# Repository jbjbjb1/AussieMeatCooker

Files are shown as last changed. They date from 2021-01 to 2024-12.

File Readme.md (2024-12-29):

# Readme

The purpose of this project is to make a device to monitor bbq air and meat temperature to cook the perfect steak! The image below shows the current progress of the project - when a perfect steak is shown, this project is functional!

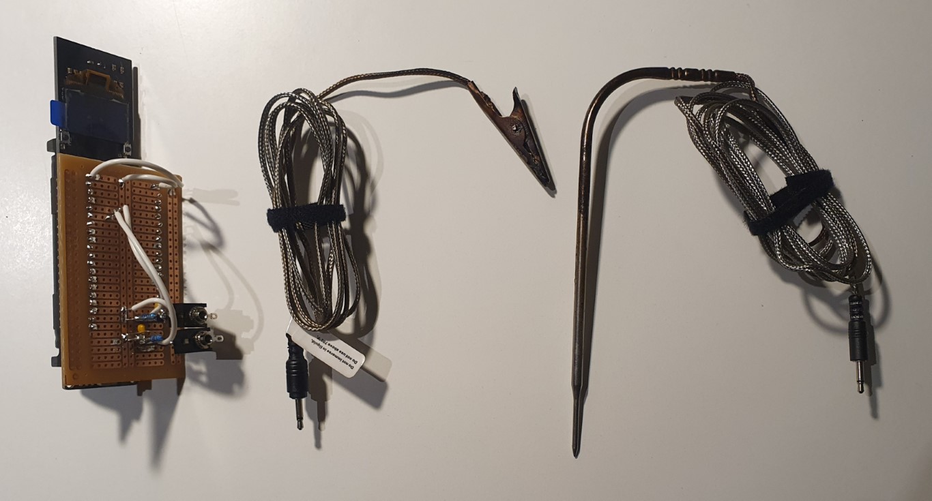
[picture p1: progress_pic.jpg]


This project is currently functional and the temperature reading has an accuracy of +/-1 deg C. It uses bluetooth to communicate via bluetooth serial (e.g. android app: https://play.google.com/store/apps/details?id=de.kai_morich.serial_bluetooth_terminal&hl=en_AU&gl=US). This project initially started as an arduino based device and spring boarded off some great work done here: https://forum.arduino.cc/index.php?topic=231655.0, but since then it has moved to the ESP32 for a more compact design with inbuilt bluetooth functionality.

## Branches
* The "master" branch is the lastest functional ESP32 version of the meat cooker. 
* The "dev" branch is the working branch for new ESP32 features.
* The "arduino" branch is an archive of where this project got up to on the Arduino Uno.

## Next steps
* Get display working on ESP32 to show temperatures
* Refactor code
* Improve app interface
* 3D print case
* Improve reading range so air sensor can work down to 0 C (limited by ESP32 only being able to measure ADC from ~0.2V). 

## Items (all prices $AUD)
* 1 x meat sensor replacement Inkbird, $11.99 + $1.99, https://www.ebay.com.au/itm/PROBE-for-INKBIRD-IBT-4X-meat-thermometer-replacement-Accessories-REPLACE-sensor/222779014478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
* 1 x bbq clip sensor replacement Inkbird, $10.99 + $1.99, https://www.ebay.com.au/itm/PROBE-Inkbird-cooking-thermometer-sensor-replacement-grill-clip-cable-replace/322770203997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
* 2 x 2.5MM Stereo Chassis Socket, $1.85, https://www.jaycar.com.au/2-5mm-stereo-chassis-socket/p/PS0107
* 1 x ESP32 WOOROM-32 DEV board, ~$26
* 1 x breadboard PCB, ~$5
* 2 x 0.1 uF capacitor
* 1 x 1 kohm resistor
* 1 x 25 kohm resistor
* 1 x 40 pin female pin header
* Thin wire

## How to use
* Connect sensors by 2.5mm jacks
* Turn ESP32 on and connect to bluetooth
* Start cooking!

## Steps completed (newest on top)
* Fixed issue with sensors not reading correct temperature range
* Implement multisampling for esp32 adc (see example code here: https://github.com/espressif/esp-idf/blob/aaf12390eb14b95589acd98db5c268a2e56bb67e/examples/peripherals/adc/main/adc1_example_main.c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 and explanation here: https://docs.espressif.com/projects/esp-idf/en/latest/esp32/api-reference/peripherals/adc.html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)
* Check voltage divider resistances allow adequate analogue to digital conversion. For example, ESP32 can only measure between 0.2-3.08V effectively (which for the air sensor is 55C - 380C and meat sensor is <-10 C - >110 C). 
* Setup ESP32 ADC converter (details: https://docs.espressif.com/projects/esp-idf/en/latest/esp32/api-reference/peripherals/adc.html)
* Put on ESP32 board with bluetooth (similar to https://github.com/dereulenspiegel/ibbq-gateway)
* Added functionality for rate of change of temperature
* Sensors arrived, did calibration and calculated Steinhart-Hart model coefficients
* Arduino screen working (I2C to the 1602 LCD) and showing temperatures
* Got code working, used potentiometer to simulate different temperatures (as resistances)

## Backend steps
* cmd -> monitor to see what port
* pio: upload system image
* pio: upload and monitor

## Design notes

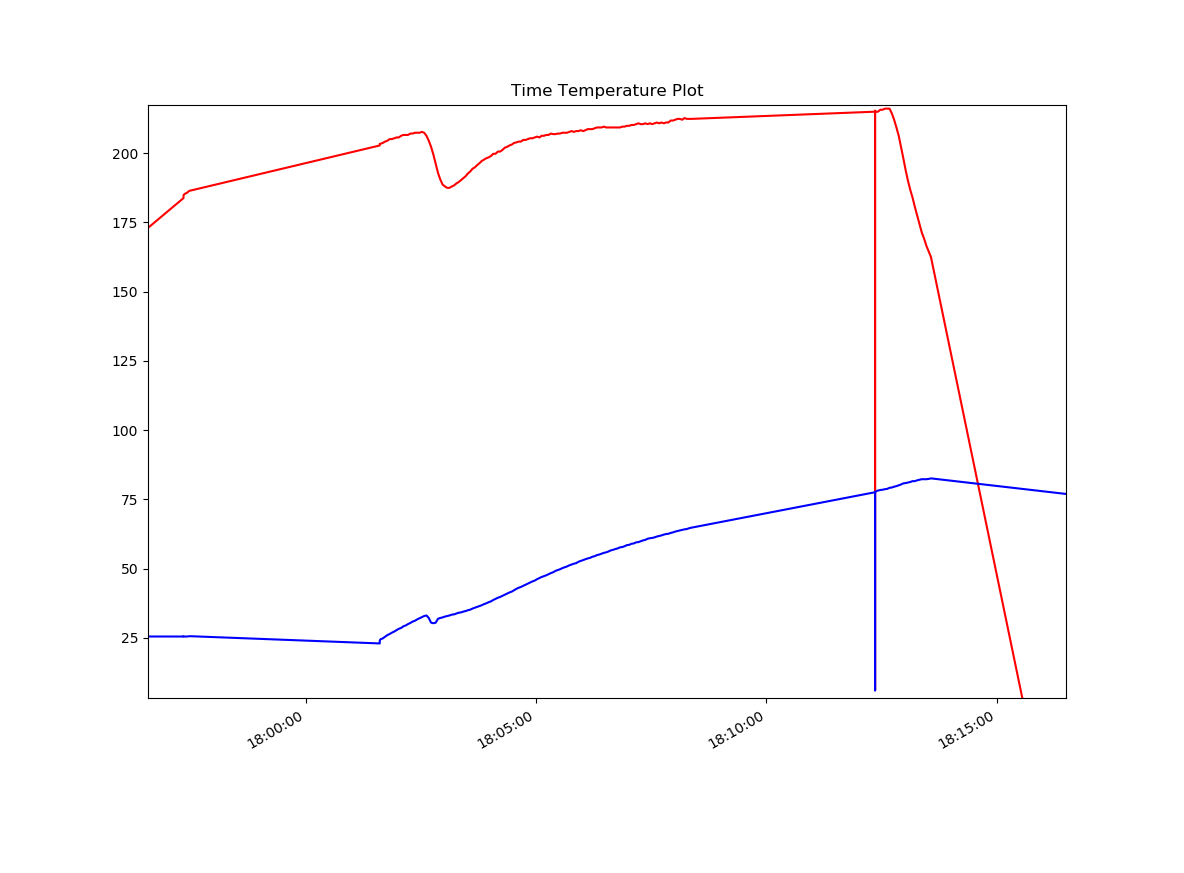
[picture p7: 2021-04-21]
supporting docs/Python scripts/sample data/serial_20210312_174735_steaks.png

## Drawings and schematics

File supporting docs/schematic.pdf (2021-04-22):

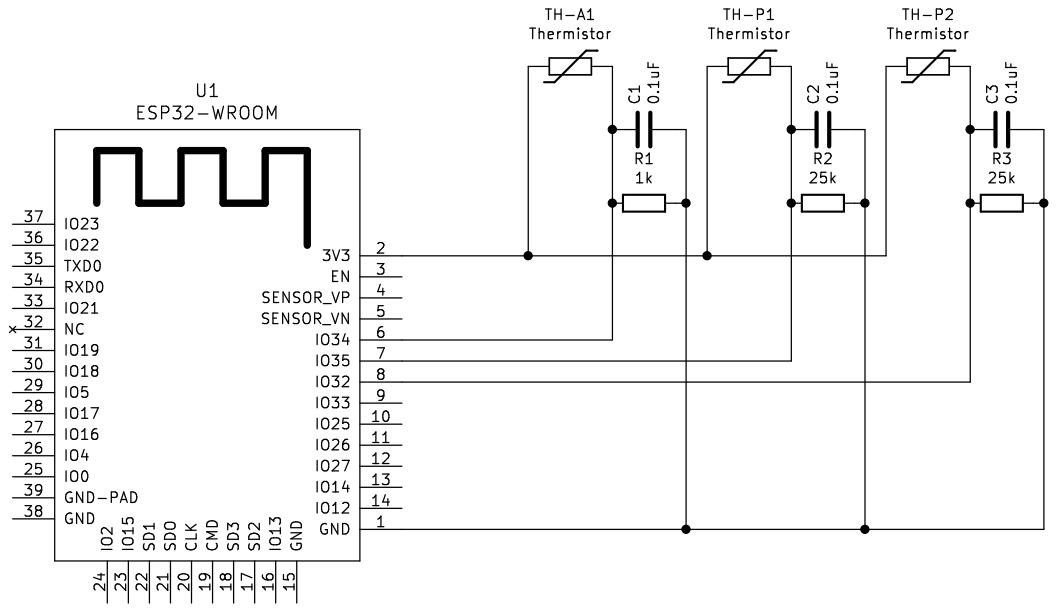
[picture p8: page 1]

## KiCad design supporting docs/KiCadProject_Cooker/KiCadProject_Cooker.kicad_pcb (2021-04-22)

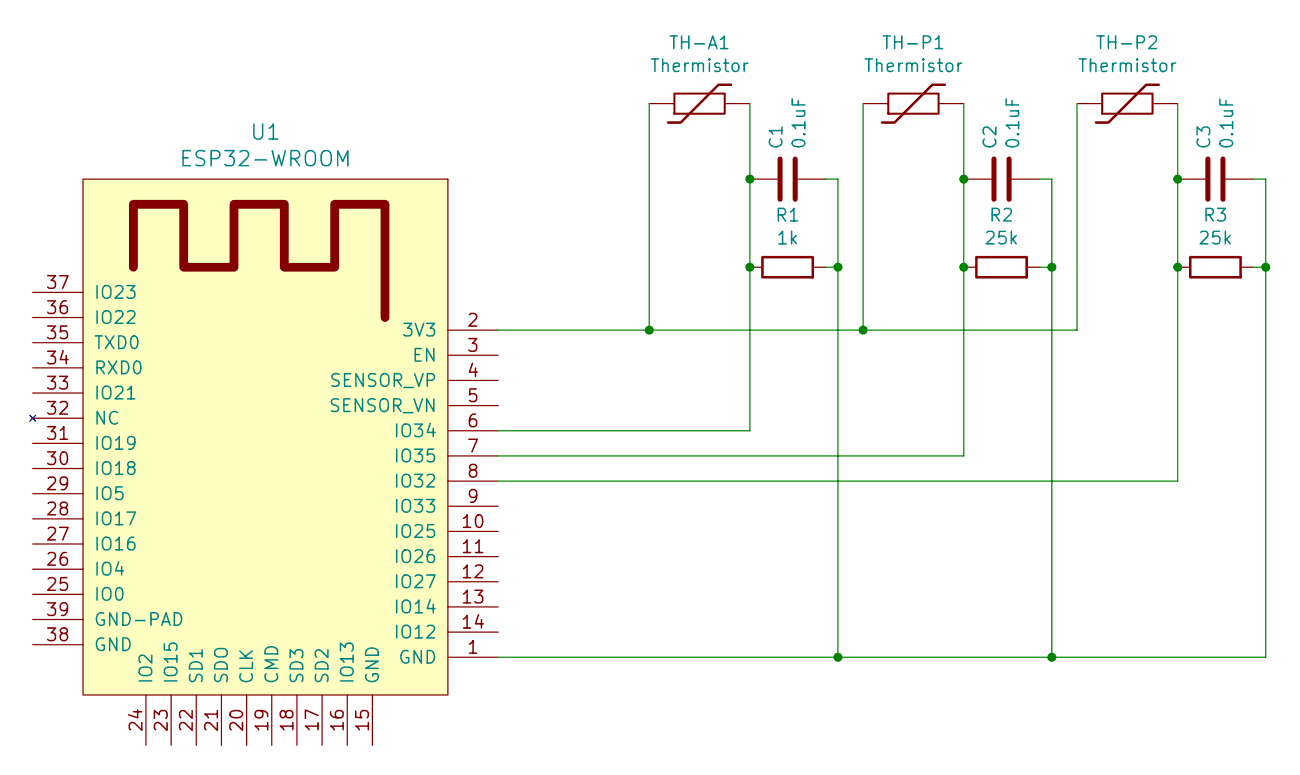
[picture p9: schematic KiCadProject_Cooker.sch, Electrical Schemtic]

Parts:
C1, C2, C3: 0.1uF; C_Disc_D3.0mm_W1.6mm_P2.50mm
R1: 1k; R_Axial_DIN0204_L3.6mm_D1.6mm_P7.62mm_Horizontal
R2, R3: 25k; R_Axial_DIN0204_L3.6mm_D1.6mm_P7.62mm_Horizontal
TH-A1: Thermistor; Banana_Jack_2Pin
TH-P1, TH-P2: Thermistor; Banana_Jack_2Pin
U1: ESP32-WROOM

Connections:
unnamed: C1.1, R1.1, TH-A1.2, U1.6 (IO34)
unnamed: C1.2, C2.2, C3.2, R1.2, R2.2, R3.2, U1.1 (GND)
unnamed: C2.1, R2.1, TH-P1.2, U1.7 (IO35)
unnamed: C3.1, R3.1, TH-P2.2, U1.8 (IO32)
unnamed: TH-A1.1, TH-P1.1, TH-P2.1, U1.2 (3V3)

Board: 2 copper layers, 10 parts (0 on the bottom side), 5 nets, no tracks yet.

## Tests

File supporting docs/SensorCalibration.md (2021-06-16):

# ESP32 Calibration
* Used ESP32 tool espefuse.py (https://github.com/espressif/esptool/wiki/espefuse) to get the calibration value for the ESP32 as documented here (https://docs.espressif.com/projects/esp-idf/en/latest/esp32/api-reference/peripherals/adc.html). On windows, with esptools installed from pip, used `python -m espefuse --port COM6 adc_info`, the  resut was: "ADC VRef calibration: 1128mV". Was not useful so far.
* There are some issues with the default ESP32 ADC (https://github.com/espressif/esp-idf/issues/164). I was able to calibrate and use within the "useable range"; see folder /ESP32_calibration.
* The A2D of the ESP32 is 12 bit (4096 different numbers). From testing done it is accurate between inputs of 18 (0.15V) - 4076 (3.15V) (with default settings).

# Sensor calibration
## Measurements
For meat sensor (sharp probe type):
Temp, Resistance (Ohm)
3, 132k
47, 20.7k
86, 5.38k

For air sensor (alagator clip type):
Temp, Resistance (Ohm)
51.1, 16.75k
94.9, 4.04k
210, 0.250k

## Steinhart-Hart model coefficients
These were calculated by the online calculator here: https://thinksrs.com/downloads/programs/Therm%20Calc/NTCCalibrator/NTCcalculator.htm

For meat sensor (sharp probe type):
A = 0.8975771660 e-3
B = 2.067767238 e-4
C = 1.742614938 e-7

For air sensor (alagator clip type):
A = 0.9482846445 e-3
B = 1.952744345 e-4
C = 2.570293116 e-7

## Determining voltage divider resistance
Following this tutorial (https://www.jameco.com/Jameco/workshop/TechTip/temperature-measurement-ntc-thermistors.html) to understand fixed resistance for voltage divider. VoltageDividerCalc.py has calculations testing paramaters. ESP32 is 12 bit so has range of 4095 values (0-4094). Then, following this paper (http://unsworks.unsw.edu.au/fapi/datastream/unsworks:56332/bin32ff80f2-1c1e-4bb2-9e86-8843f5423fbb?view=true) to find the best relationship for the fixed resistance for voltage dividers is:

R_o = (R_min + R_max)^(1/2)

### Meat sensor
For the sensor I expect they will need to work in ranges:
* Most accurate: 62 C or 74 C
* Usually: 20 C - 80 C
* Sometimes: -10 C - 110 C (248.1k - 2.62k)

So, sqrt(248.1 * 2.62) = 25.5 kOhm
So, try 25 kOhm fixed resistor value.

### BBQ air sensor
(NOTE: Need to check this sensor has the same Steinhart-Hart model coefficients as the above)
For the sensor I expect they will need to work in ranges:
* Most accurate: 220 to 300 C
* Usually: 100 - 320 C
* Sometimes: 10 - 340 C (82.47k -  0.0313k)

Calculating sqrt(82.47 * 0.0313) = 1.6 kOhm
So, try 1 kOhm fixed resistor value.

# Improvements
* Need air sensor to work from 0 C up to 340 C. Need that low temperature range.
* Use a external A2D converter if want higher accuracy.

# Completed (newest ontop)
* 2.60V is 206C on ESP32 (but on plot, 206C is 1.78V). -> Plot was not at high enough resolution.
* Consider a ADC chip for higher accuracy. -> Not needed, ESP32 sufficient accuracy.

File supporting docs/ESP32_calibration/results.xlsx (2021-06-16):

Raw Input
Supply voltage | 3.28
 | adc [] | actual (mV) | planned (mV)
 | 0 | 0 | 0
 | 0 | 50 | 50
 | 0 | 100 | 100
 | 18 | 150 | 150
 | 80 | 200 | 200
 | 135 | 250 | 250
 | 193 | 300 | 300
 | 436 | 500 | 500
 | 683 | 700 | 700
 | 916 | 900 | 900
 | 1164 | 1100 | 1100
 | 1409 | 1300 | 1300
 | 1650 | 1500 | 1500
 | 1889 | 1700 | 1700
 | 2130 | 1900 | 1900
 | 2377 | 2100 | 2100
 | 2625 | 2300 | 2300
 | 2877 | 2500 | 2500
 | 3159 | 2700 | 2700
 | 3507 | 2900 | 2900
 | 3614 | 2950 | 2950
 | 3714 | 3000 | 3000
 | 3823 | 3050 | 3050
 | 3950 | 3100 | 3100
 | 4076 | 3150 | 3150
 | 4095 | 3200 | 3200
 | 4095 | 3250 | 3250
Valid Range (200-2700 mv)
 | adc [] | actual (mV)
 | 18 | 150
 | 80 | 200
 | 135 | 250
 | 193 | 300
 | 436 | 500
 | 683 | 700 |  | 159.154392
 | 916 | 900
 | 1164 | 1100
 | 1409 | 1300
 | 1650 | 1500
 | 1889 | 1700
 | 2130 | 1900
 | 2377 | 2100
 | 2625 | 2300
 | 2877 | 2500
 | 3159 | 2700
Valid Range (2700-3100 mv)
 | adc [] | actual (mV)
 | 3159 | 2700
 | 3507 | 2900
 | 3614 | 2950
 | 3714 | 3000
 | 3823 | 3050
 | 3950 | 3100
 | 4076 | 3150

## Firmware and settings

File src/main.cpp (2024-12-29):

//Title: Meat Cooker - Digital BBQ Thermometer

#include <Arduino.h>
#include <WiFi.h>
#include <ESPAsyncWebServer.h>
#include <SPI.h>
#include <arduino-timer.h>
#include "Temperature.h"
#include <SPIFFS.h>

const char* ssid = "AussieMeatCooker1";
const char* password = "12345678";

float update_r = 5000;          // Update rate for sensors, milliseconds (match to index.html)

auto t = timer_create_default(); // create a timer with default settings

AsyncWebServer server(80);


void setup() {
    Serial.begin(115200);

    // Initialize Wi-Fi as Access Point
    WiFi.softAP(ssid, password); // Start the access point
    Serial.println("Access Point Started");
    Serial.print("SSID: ");
    Serial.println(ssid);

    // Print the IP address of the ESP32 AP
    Serial.print("IP Address: ");
    Serial.println(WiFi.softAPIP());

    // Setup SPIFFS which hosts the index.html website
    if (!SPIFFS.begin(true)) {
    Serial.println("An error occurred while mounting SPIFFS");
    return;
    }

    // Start the web server
    server.on("/", HTTP_GET, [](AsyncWebServerRequest *request){
        request->send(SPIFFS, "/index.html", "text/html");
    });
    Serial.println("Server started, listening for connections...");

    
    server.on("/temperature", HTTP_GET, [](AsyncWebServerRequest *request){
    String json = "{\"meat\":" + String(meat) + 
                  ", \"air\":" + String(air) + 
                  ", \"meat_r\":" + String(meat_r) + 
                  ", \"air_r\":" + String(air_r) + "}";
    request->send(200, "application/json", json);
    });


    // Start the server
    server.begin();

    // Set up periodic tasks
    t.every(update_r, updateTemp);
    t.every(update_r, updateTempRate);
}


void loop() {
    // The main loop just ticks over the timer:
    t.tick();
}

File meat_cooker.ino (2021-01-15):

//Title: Meat Cooker - Digital BBQ Thermometer

// Part 1: This initializes the LCD using the I2C converter and the global variables that we will need:

#include <SPI.h>
#include <Event.h>
#include <Timer.h>
#include <LiquidCrystal_I2C.h>
#include <math.h>
                       
LiquidCrystal_I2C lcd(0x27,16,2);

Timer t;

float air;                      // BBQ air temperature
float meat;                     // Meat temperature
float vin = 4.98;               // DC Voltage as measured with DMM between +5V and GND
float r2 = 20000;               // Resistance in ohms of your fixed resistor

float A = 1.839472271 * pow(10, -3);      // "A" Coeffecient in Steinhart-Hart Equation
float B = 0.6807883650 * pow(10, -4);     // "B"
float C = 6.022892289 * pow(10, -7);      // "C"

// Part 2: The "Setup" function displays connection info on the LCD, and calls our other functions (readSensors and updateDisplay) on a fixed interval based on Timer "t":

void setup()
{
    Serial.begin(9600);
    analogReference(DEFAULT);                    // Use default 5V reference
    lcd.init();
    lcd.backlight();
    lcd.clear();
    lcd.home();
    lcd.print("Meat Cooker!");
    Serial.println("Meat Cooker!");             // Output to serial too
    delay(1000); 

    t.every(4000, readSensors);
    t.every(4000, updateDisplay);
    t.every(4000, updateSerial);  
}                      

// Part 3: The main loop essentially just updates the timer:

void loop()
{
    t.update(); 
}

// Part 4: The "readSensors" function does exactly that; it reads the sensor and calculates the temperature:

void readSensors()
{
    float a0 = analogRead(A0);                                   // This reads the "voltage" value on A0. Value is actually divided into 1024 steps from 0-1023.
    float v0 = a0 * (5/1024);                                    // Converts A0 value to an actual voltage (5.0V / 1024 steps)
    float r0 = (((r2 * vin) / v0) - r2);                         // Calculates resistance value of thermistor based on fixed resistor value and measured voltage
    float logr0 = log(r0);                                       // Natural log of thermistor resistance used in Steinhart-Hart Equation
    float logcubed0 = logr0 * logr0 * logr0;                     // The cube of the above value
    float k0 = 1.0 / (A + (B * logr0) + (C * logcubed0));        // Steinhart-Hart Equation to calculate temperature in Kelvin
    float c0 = k0 - 273.15;                                      // Convert temperature K to C

if (isnan(c0))                                                   // If value is not a number, assign an arbitrary value
{
   air = int(1);
}
else
{
    air = c0;                                                    // Otherwise use the calculated value
}

float a1 = analogRead(A1);                                       // Same code as above. Repeat for as many sensors as you need to connect.
float v1 = a1 * (5/1024);
float r1 = (((r2 * vin) / v1) - r2);
float logr1 = log(r1);
float logcubed1 = logr1 * logr1 * logr1;
float k1 = 1.0 / (A + (B * logr1) + (C * logcubed1));
float c1 = k1 - 273.15;  

if (isnan(c1))
{
    meat = int(1);
}
else
{
    meat = c1;
}
}

// Part 5: The "updateDisplay" function displays the temperature values on the LCD:

void updateDisplay()
{
    lcd.clear();

    lcd.setCursor(0,0);
    lcd.print("BBQ :");
    lcd.print(air, 1);
    lcd.print(" C");
    
    lcd.setCursor(0,1);
    lcd.print("Meat:");
    lcd.print(meat, 1);
    lcd.print(" C");
}

// Part 6: Update the serial output:

void updateSerial()
{
    
    Serial.print("BBQ: ");
    Serial.print(air, 1);
    Serial.print(" C, ");
    Serial.print("Meat: ");
    Serial.print(meat, 1);
    Serial.println(" C");
}

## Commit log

2021-01-14 progressing voltage divider logic
2021-01-14 base code for voltage divider working
2021-01-15 determined optimum fixed res. for meat sensor
2021-01-15 Updated to do test with meat sensor
2021-01-29 Air and meat sensors working, rate showing
2021-01-30 Fixed probe labels, fixed error in temp rate code
    [meat_cooker.ino]
2021-01-30 Basic plotting of log for temperature working
2021-02-05 Arduino prototype board pic
2021-04-21 added kicad layout for esp32
    [ESP32-Footprints.kicad_pcb, ESP32-Footprints.sch, KiCadProject_Cooker.kicad_pcb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]
2021-04-21 progress on setting up esp32 adc
2021-04-22 baisc working but not good temperature range
2021-04-22 working and functional
    [KiCadProject_Cooker.kicad_pcb, KiCadProject_Cooker.sch, results.xlsx]
2021-04-26 updated to do 64 samples each time
    [results.xlsx]
2021-04-26 pushed limit esp32 can read high air temp a little
2021-06-16 fixed issue cutting down range
    [results.xlsx]
2024-12-24 re-arrange folder to have files at top level
    [ESP32-Footprints.kicad_pcb, ESP32-Footprints.sch, KiCadProject_Cooker.kicad_pcb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]
